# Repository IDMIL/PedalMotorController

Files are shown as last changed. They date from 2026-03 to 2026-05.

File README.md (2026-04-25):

# PedalMotorController: An Arduino platform for programmatically turning pedal knobs

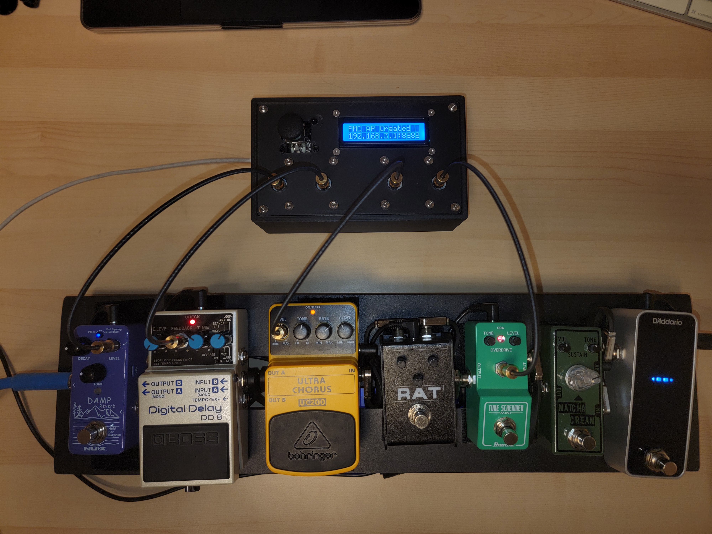
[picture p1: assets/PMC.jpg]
PMC


## Description

The Pedal Motor Controller (abbreviated PMC) is a device that mechanically turns guitar pedal knobs using gyroscopic data for expressive guitar performance. Users can connect their phone over UDP to an Arduino hub that translates their phone's gyroscopic movements into knob turns. The knob turns can then influence music performed with the pedals.

If the user attaches their phone to the guitar headstock, then movements of the guitar will have a direct correlation to sonic output. This is especially relevant for gestural research, as it provides a platform for investigating the relationship between performance gestures and musical style.

## Usage

1. Remove the knob from the desired pedal parameter and attach a coupler to the exposed potentiometer
2. Download the [Serial Sensor](https://play.google.com/store/apps/details?id=com.karl.serialsensor) app on your phone
3. Turn on the PMC and connect to its WiFi access point on your phone (SSID and password are both "PedalMotorController")
4. In Serial Sensor, under the Sensors tab, select only **Gyroscope**
5. Under the Connection tab, select **Network** and input the IP address and port shown on the PMC's display
6. Press the play button in SerialSensor when you are ready to send data (you may need to do this twice for it to register)

## Installation

(This guide is only for those who want to make their own PMC.)

1. Clone this repository to your machine.
2. In `src`, zip each folder into an individual file, EXCLUDING `src/Main`.
3. Install the [Arduino IDE](https://www.arduino.cc/en/software/) and launch. Under the Sketch tab, select `Include Library > Add .ZIP Library...`
4. Select and install each of the zipped folders you created in step 2.
5. Under the `Libraries` tab on the left (bookshelf icon), search and install `AccelStepper` and `arduino-timer`. These are external libraries that the PMC uses.
6. Once all zips are installed, make sure the program compiles by clicking the checkmark on the top left (labeled `Verify`).
7. Finally, connect an Arduino GIGA to your computer, select it in the top left, and select `Upload`.

## Hardware

### Fritzing Diagram

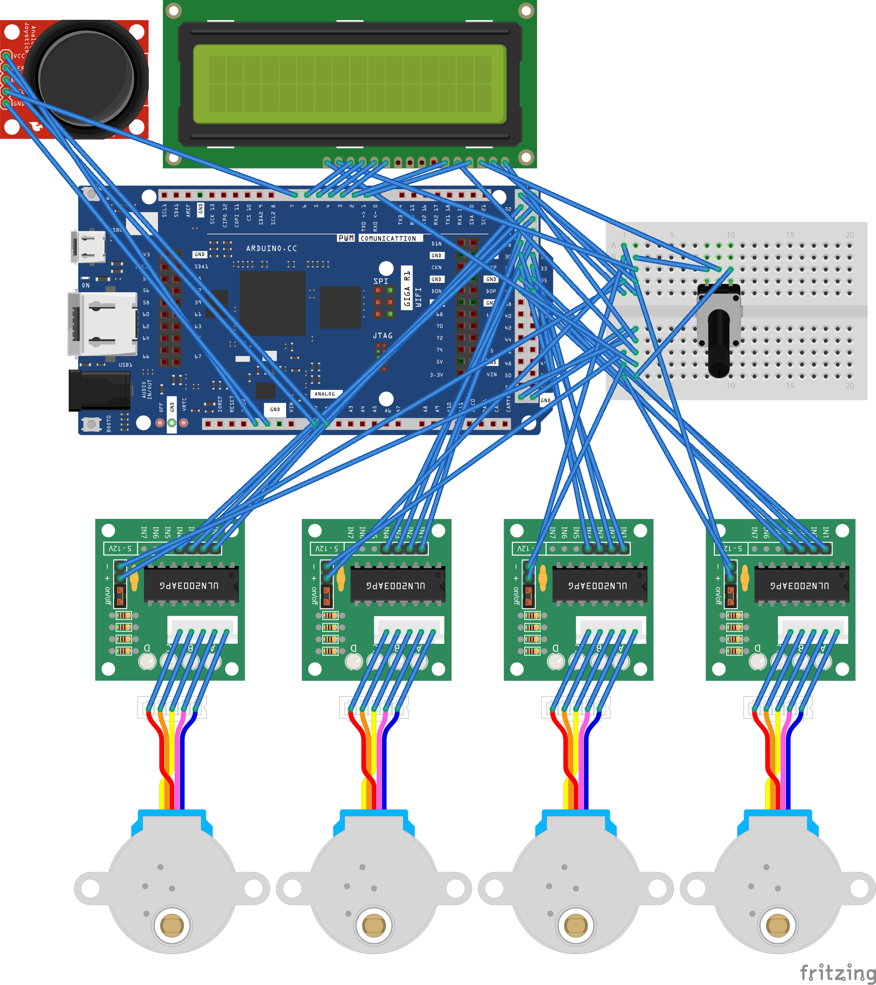
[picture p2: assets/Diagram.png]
Fritzing Diagram


### Parts List

* Arduino GIGA R1 WiFi
* 4x 28BYJ-48 stepper motors
* 4x ULN2003 stepper motor drivers
* LCD1602 2x16 LCD display
* Joystick module
* Mini breadboard
* 3-pin potentiometer
* Jumper wires

## Credits

Created by Ian Doherty, fall 2025 through winter 2026, at McGill University's Input Devices and Music Interaction Laboratory (IDMIL).

This project was inspired by similar knob-turning devices, including the [Toe-N Control Pedal](https://dukedesigns3d.com/products/toe-n-control-v1-universal-expression-59517), the [Gecko Tool](https://geckotool.com/), and the [Knoblin](https://github.com/narad/knoblin). **The ideas underpinning this project are not novel**; my sole intent is to explore controlling effect automation using gestures.

The hardware diagram was generated using [Fritzing](https://fritzing.org), [fritzing-parts](https://github.com/mgesteiro/fritzing-parts/tree/main) (28BYJ-48, ULN2003), and [this Arduino GIGA R1 WiFi Fritzing part](https://forum.fritzing.org/t/arduino-giga-r1-wifi/20039).

Special thanks to Dr. Marcelo Wanderley for his supervision and Darryl Cameron for his assistance in assembly.

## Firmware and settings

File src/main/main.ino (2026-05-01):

// Arduino Standard Libs
// #include <KVStore.h>
// #include <kvstore_global_api.h>
#include <LiquidCrystal.h>
#include <WiFi.h>

// Custom Libraries
#include <Joystick.h>
#include <MotorInfo.h>

#include <Menu.h>
#include <AxisSelectMenu.h>
#include <CurveSelectMenu.h>
#include <MultiplierSelectMenu.h>
#include <SplashScreen.h>
#include <StepperAngleMenu.h>
#include <StepperPositionMenu.h>

// External Libraries
#include <AccelStepper.h>
#include <arduino-timer.h>

// Constants
const unsigned long     BAUD_RATE = 38400;
const long              MAX_STEPS = 2048;
const unsigned          UDP_PORT = 8888;
const String            SSID = "PedalMotorController";

// Globals
LiquidCrystal           lcd(1, 2, 3, 4, 5, 6);
WiFiUDP                 udp;
SerialSensorGyro        ssg(&udp);
Joystick                joystick(7, A0, A1);
auto                    disconnectTimer = timer_create_default();
SplashScreen            splashScreen(&lcd, SSID, UDP_PORT);
int                     currentMotor = 0;
int                     currentMenu = 0;
bool                    firstTime = true;

// Motors
MotorInfo motors[4] = {
    MotorInfo(
        0, 
        AccelStepper(AccelStepper::MotorInterfaceType::FULL4WIRE, 22, 24, 23, 25), 
        MAX_STEPS, 
        &ssg, &lcd, &joystick
    ),
    MotorInfo(
        1, 
        AccelStepper(AccelStepper::MotorInterfaceType::FULL4WIRE, 26, 28, 27, 29), 
        MAX_STEPS, 
        &ssg, &lcd, &joystick
    ),
    MotorInfo(
        2, 
        AccelStepper(AccelStepper::MotorInterfaceType::FULL4WIRE, 30, 32, 31, 33), 
        MAX_STEPS, 
        &ssg, &lcd, &joystick
    ),
    MotorInfo(
        3, 
        AccelStepper(AccelStepper::MotorInterfaceType::FULL4WIRE, 34, 36, 35, 37), 
        MAX_STEPS, 
        &ssg, &lcd, &joystick
    )
};

// Disconnect callback
bool onDisconnect(void*) {
    if (!firstTime) {
        lcd.clear();
        splashScreen.init();
        firstTime = true;
    }
    return true;
}

void setup() {
    // Serial
    // Serial.begin(BAUD_RATE);
    // while (!Serial);

    Serial.println("PedalMotorController");
    Serial.println("Booting...\n");

    // Motors
    for (int i = 0; i < 4; i++) {
        motors[i].stepper.setMaxSpeed(1000);
        motors[i].stepper.setSpeed(1);
    }

    // Joystick
    joystick.onClick = [motors, currentMotor, currentMenu] () { 
        motors[currentMotor].menus[currentMenu]->toggleSelected(); 
    };

    // LCD
    lcd.begin(16, 2);
    lcd.clear();

    // Networking
    WiFi.beginAP(SSID.c_str(), SSID.c_str());
    udp.begin(UDP_PORT);

    // Debug Info
    Serial.print("PMC: SSID: "); Serial.println(SSID);
    Serial.print("PMC: UDP port: "); Serial.println(UDP_PORT);
    Serial.print("PMC: Local IP address: "); Serial.println(WiFi.localIP());
    Serial.print("\n");

    // Splash screen
    splashScreen.init();
}

void loop() {
    if (udp.parsePacket()) {
        disconnectTimer.cancel();

        // Always read the frame
        ssg.readFrame();

        // Always run the motors while there's data
        for (MotorInfo& motor : motors)
            motor.run();

        Menu* visibleMenu = motors[currentMotor].menus[currentMenu];

        // Initializing the first menu
        if (firstTime) {
            lcd.clear();
            visibleMenu->init();
            firstTime = false;
        }

        // Always update the menu & joystick
        visibleMenu->update();
        joystick.update();

        if (!visibleMenu->isSelected()) {
            bool menuChanged = false;

            Joystick::Action action = joystick.getCurrentAction();
            // Serial.println(Joystick::actionToString(action).c_str());

            // 4 motors, 5 menus each
            // Right -> go to next motor
            // Left -> go to previous motor
            // Down -> go to next menu
            // Up -> go to previous menu
            switch (action) {
                case Joystick::Action::W:
                    if (currentMotor == 0)
                        currentMotor = 3;
                    else
                        currentMotor = (currentMotor - 1) % 4;
                    menuChanged = true;
                    break;
                case Joystick::Action::E:
                    currentMotor = (currentMotor + 1) % 4;
                    menuChanged = true;
                    break;
                case Joystick::Action::S:
                    if (currentMenu == 0)
                        currentMenu = 4;
                    else
                        currentMenu = (currentMenu - 1) % 5;
                    menuChanged = true;
                    break;
                case Joystick::Action::N:
                    currentMenu = (currentMenu + 1) % 5;
                    menuChanged = true;
                    break;
                default:
                    break;
            }

            if (menuChanged) {
                lcd.clear();
                motors[currentMotor].menus[currentMenu]->init();
            }
        }
    }
    else {
        if (disconnectTimer.empty())
            disconnectTimer.in(1000, onDisconnect); // mark disconnected after 1 second
        disconnectTimer.tick();
    }
}

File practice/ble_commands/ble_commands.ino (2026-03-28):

#include <SoftwareSerial.h>

const int ENABLE_PIN = 7;
const int TX_PIN = 5;
const int RX_PIN = 6;

const unsigned long BAUD_RATE = 38400;

SoftwareSerial bleSerial(TX_PIN, RX_PIN);

void setup() {
  pinMode(ENABLE_PIN, OUTPUT);
  digitalWrite(ENABLE_PIN, HIGH);

  Serial.begin(BAUD_RATE);
  Serial.println("Enter AT Commands");
  
  bleSerial.begin(BAUD_RATE);
}

void loop() {
  if (Serial.available())
    bleSerial.write(Serial.read());

  if (bleSerial.available())
    Serial.write(bleSerial.read());
}

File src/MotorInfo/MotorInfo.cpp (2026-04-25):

#include "MotorInfo.h"

#include <Arduino.h>

#define sgn(x) (x < 0 ? -1 : 1)

MotorInfo::MotorInfo(int motorNum, AccelStepper stepper, long maxSteps, SerialSensorGyro* ssg, LiquidCrystal* lcd, Joystick* joystick) :
    motorNum(motorNum),
    stepper(stepper),
    maxSteps(maxSteps),
    ssg(ssg),
    lcd(lcd),
    joystick(joystick),
    stepperPositionMenu(lcd, this), 
    stepperAngleMenu(lcd, this), 
    axisSelectMenu(lcd, this, joystick), 
    multiplierSelectMenu(lcd, this, joystick), 
    curveSelectMenu(lcd, this, joystick),
    menus{ &stepperPositionMenu, &stepperAngleMenu, &axisSelectMenu, &multiplierSelectMenu, &curveSelectMenu }
{
}

void MotorInfo::run() {
    float gyroData = 0.0f;

    switch (axis) {
        case MotorInfo::Axis::X:
            gyroData = ssg->getX();
            break;
        case MotorInfo::Axis::Y:
            gyroData = ssg->getY();
            break;
        case MotorInfo::Axis::Z:
            gyroData = ssg->getZ();
            break;
    }

    double velocity = gyroData * multiplier;
    currentStep = stepper.currentPosition();

    switch (curve) {
        case Curve::LINEAR:
            velocity = velocity;
            break;
        case Curve::EXPONENTIAL:
            velocity = exp(gyroData); // omitting multiplier, since this (obviously...) grows really fast!
            break;
        case Curve::LOGARITHMIC:
            if (velocity != 0) velocity = sgn(velocity) * log(abs(velocity));
            break;
        case Curve::QUADRATIC:
            velocity = pow(velocity, 2);
            break;
    }

    stepper.setSpeed(velocity); 

    stepper.runSpeed();
}

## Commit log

2026-03-28 Build functionality for multiple motors; encapsulate behavior
    [Diagram.fzz]
2026-03-28 Bug fix until compilable
    [AxisSelectMenu.cpp, CurveSelectMenu.cpp, Joystick.cpp]
2026-04-12 Push local changes; fix joystick navigation for menus
    [AxisSelectMenu.cpp, CurveSelectMenu.cpp, Joystick.cpp]
2026-04-12 Add photos; update diagram; update readme
    [Diagram.fzz]
2026-04-25 Lots of bug fixes
    [AxisSelectMenu.cpp, CurveSelectMenu.cpp, Joystick.cpp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]
2026-04-26 Fix overreading of SerialSensor frames
    [MultiplierSelectMenu.cpp, main.ino]
